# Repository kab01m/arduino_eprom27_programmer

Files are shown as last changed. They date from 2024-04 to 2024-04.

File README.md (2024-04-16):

# EPROM 27-series Arduino-based programmer

Work in-progress of a project of easy-to-use programmer for EPROM 27-series based on Arduino.

*Download GUI application and Arduino sketch from "Releases".*

Supported chips:
 * 27C16 (connects from 3 to 26 leg DIP28 socket)
 * 27C32 (connects from 3 to 26 leg DIP28 socket)
 * 27C64
 * 27C128
 * 27C256
 * 27C512
 * Dallas DS1225 NVRAM

## Installation

Order PCB from gerber files, assemble the board. Use BOM to find components.

If non-Arduino MCU was used you have to flash bootloader from Arduino IDE using ICSP connector. 

If first time assembled you have to load sketch.ino into Arduino IDE and flash your Arduino.

Always check programming voltage before inserting new chip to program.

Run GUI application and choose serial port.

## Schematics

[Initial project](<https://github.com/bouletmarc/BMBurner>):
* Was made in DIP packages.
* No sources.
* Windows-only application.

[Walhi project](<https://github.com/walhi/arduino_eprom27_programmer>):
* Made in Eagle.
* 50/50 SMD/DIP.
* New Arduino sources.
* Windows/Linux Qt-based light GUI application.

[Radionews fork](<https://github.com/Radionews/arduino_eprom27_programmer>):
* Refactored in EasyEDA.
* Uses SPI for logic.
* Mostly SMD components.
* Uses GUI application from above.

[This project](<https://github.com/kab01m/arduino_eprom27_programmer>):
* Translated to KiCad EDA.
* SMD components whereever it was possible.
* Arduino is now not detachable.
* No schematic difference from above.
* Previous software used.

Schematics

Schematic

Assembled picture

PCB

## Software

Software is taken from [Walhi project](<https://github.com/walhi/arduino_eprom27_programmer>).

Functions:

 * Read EEPROM/NVRAM.
 * Write EEPROM/NVRAM.
 * Verify chip and check if it is zeroed.
 * Programming voltage check (available for AVR in TQFP case)

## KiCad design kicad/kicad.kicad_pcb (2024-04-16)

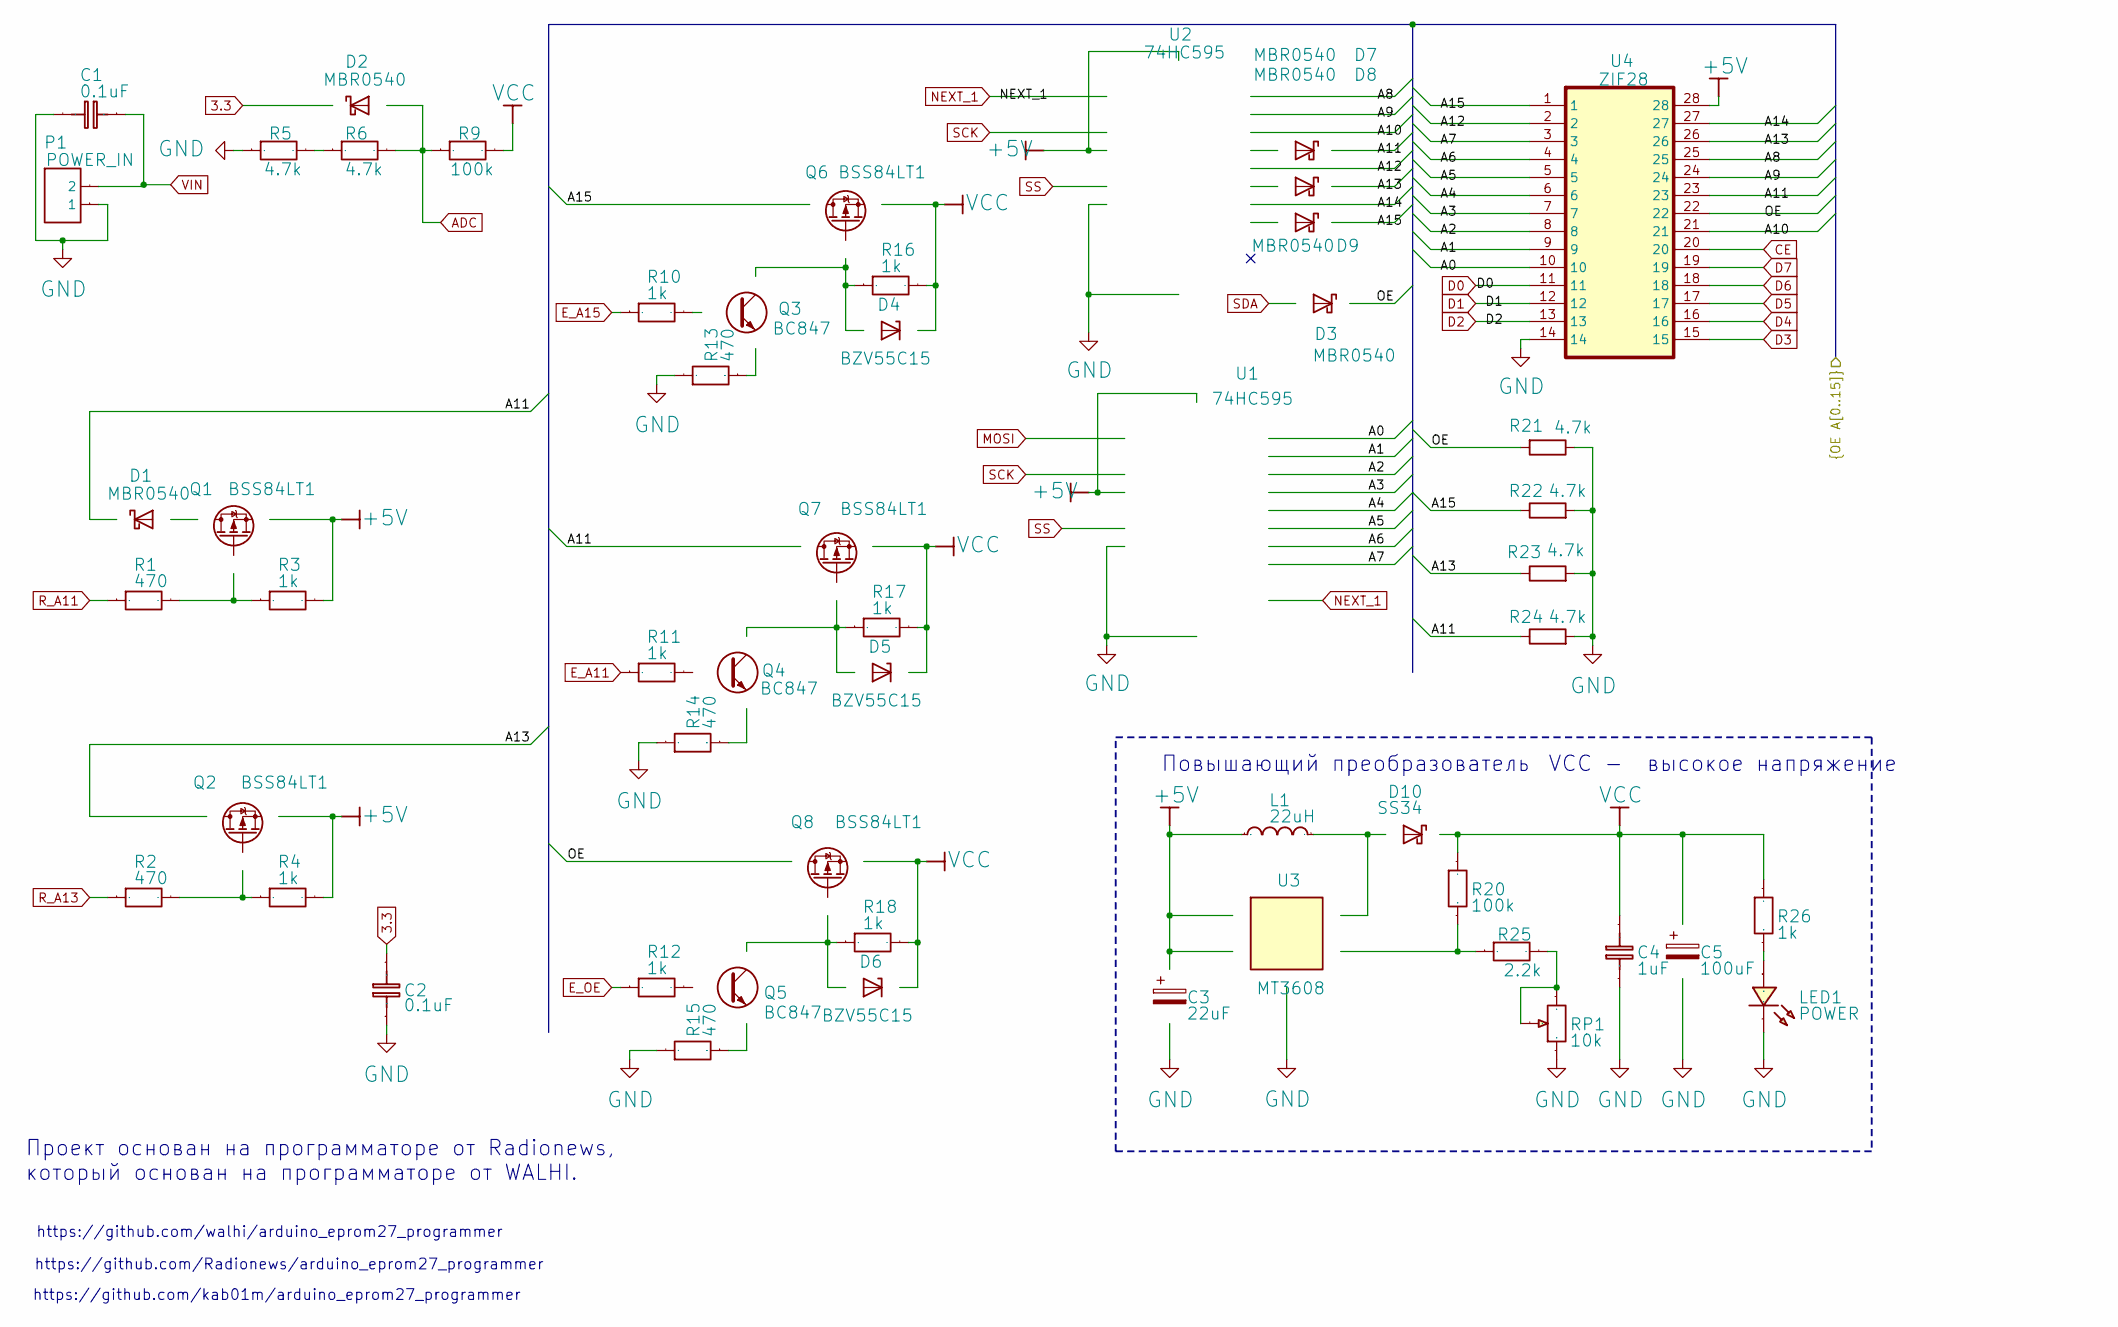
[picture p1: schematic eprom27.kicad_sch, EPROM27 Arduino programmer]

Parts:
C1, C2: 0.1uF; C_0805_2012Metric_Pad1.18x1.45mm_HandSolder
C3: 22uF; CP_Elec_5x5.4
C4: 1uF; C_1206_3216Metric_Pad1.33x1.80mm_HandSolder
C5: 100uF; CP_Elec_8x6.2
D1, D2, D3, D7, D8, D9: MBR0540; D_SOD-123
D4, D5, D6: BZV55C15; D_MiniMELF
D10: SS34; D_SMA
L1: 22uH; L_Chilisin_BMRx00060630
LED1: POWER; LED_0805_2012Metric_Pad1.15x1.40mm_HandSolder
P1: POWER_IN; JST_NV_B02P-NV_1x02_P5.00mm_Vertical
Q1, Q2, Q6, Q7, Q8: BSS84LT1; SOT-23
Q3, Q4, Q5: BC847; SOT-23
R1, R2, R13, R14, R15: 470; R_0805_2012Metric_Pad1.20x1.40mm_HandSolder
R3, R4, R10, R11, R12, R16, R17, R18, R26: 1k; R_0805_2012Metric_Pad1.20x1.40mm_HandSolder
R5, R6, R21, R22, R23, R24: 4.7k; R_0805_2012Metric_Pad1.20x1.40mm_HandSolder
R9, R20: 100k; R_0805_2012Metric_Pad1.20x1.40mm_HandSolder
R25: 2.2k; R_0805_2012Metric_Pad1.20x1.40mm_HandSolder
RP1: 10k; Potentiometer_Bourns_3224W_Vertical
U1, U2: 74HC595; SOIC-16_3.9x9.9mm_P1.27mm
U3: MT3608; SOT-23-6
U4: ZIF28; DIP_Socket-28_W11.9_W12.7_W15.24_W17.78_W18.5_3M_228-1277-0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

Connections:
3.3: C2.2, D2.1 (K); also elsewhere on the board
+5V: C3.1, L1.1, Q1.2 (S), Q2.2 (S), R3.2, R4.2, U1.10 (~SRCLR), U1.16 (VCC), U2.10 (~SRCLR), U2.16 (VCC), U3.4 (EN), U3.5 (IN), U4.28; also elsewhere on the board
/EPROM27/A0: U1.15 (QA), U4.10
/EPROM27/A1: U1.1 (QB), U4.9
/EPROM27/A2: U1.2 (QC), U4.8
/EPROM27/A3: U1.3 (QD), U4.7
/EPROM27/A4: U1.4 (QE), U4.6
/EPROM27/A5: U1.5 (QF), U4.5
/EPROM27/A6: U1.6 (QG), U4.4
/EPROM27/A7: U1.7 (QH), U4.3
/EPROM27/A8: U2.15 (QA), U4.25
/EPROM27/A9: U2.1 (QB), U4.24
/EPROM27/A10: U2.2 (QC), U4.21
/EPROM27/A11: D1.1 (K), D7.1 (K), Q7.3 (D), R24.1, U4.23
/EPROM27/A12: U2.4 (QE), U4.2
/EPROM27/A13: D8.1 (K), Q2.3 (D), R23.1, U4.26
/EPROM27/A14: U2.6 (QG), U4.27
/EPROM27/A15: D9.1 (K), Q6.3 (D), R22.1, U4.1
/EPROM27/OE: D3.1 (K), Q8.3 (D), R21.2, U4.22
ADC: D2.2 (A), R6.2, R9.1; also elsewhere on the board
CE: U4.20; also elsewhere on the board
D0: U4.11; also elsewhere on the board
D1: U4.12; also elsewhere on the board
D2: U4.13; also elsewhere on the board
D3: U4.15; also elsewhere on the board
D4: U4.16; also elsewhere on the board
D5: U4.17; also elsewhere on the board
D6: U4.18; also elsewhere on the board
D7: U4.19; also elsewhere on the board
E_A11: R11.1; also elsewhere on the board
E_A15: R10.1; also elsewhere on the board
E_OE: R12.1; also elsewhere on the board
MISO: R1.1; also elsewhere on the board
MOSI: U1.14 (SER); also elsewhere on the board
NEXT_1: U1.9 (QH'), U2.14 (SER)
unnamed: D1.2 (A), Q1.3 (D)
unnamed: D4.2 (A), Q3.3 (C), Q6.1 (G), R16.1
unnamed: D5.2 (A), Q4.3 (C), Q7.1 (G), R17.1
unnamed: D6.2 (A), Q5.3 (C), Q8.1 (G), R18.1
unnamed: D7.2 (A), U2.3 (QD)
unnamed: D8.2 (A), U2.5 (QF)
unnamed: D9.2 (A), U2.7 (QH)
unnamed: D10.2 (A), L1.2, U3.1 (SW)
unnamed: LED1.1, R26.1
unnamed: Q1.1 (G), R1.2, R3.1
unnamed: Q2.1 (G), R2.2, R4.1
unnamed: Q3.1 (B), R10.2
unnamed: Q3.2 (E), R13.1
unnamed: Q4.1 (B), R11.2
unnamed: Q4.2 (E), R14.1
unnamed: Q5.1 (B), R12.2
unnamed: Q5.2 (E), R15.1
unnamed: R5.2, R6.1
unnamed: R25.2, RP1.2, RP1.3
unnamed: R20.1, R25.1, U3.3 (FB)
R_A13: R2.1; also elsewhere on the board
SCK: U1.11 (SRCLK), U2.11 (SRCLK); also elsewhere on the board
SDA: D3.2 (A); also elsewhere on the board
SS: U1.12 (RCLK), U2.12 (RCLK); also elsewhere on the board
VCC: C4.2, C5.1, D4.1 (K), D5.1 (K), D6.1 (K), D10.1 (K), Q6.2 (S), Q7.2 (S), Q8.2 (S), R9.2, R16.2, R17.2, R18.2, R20.2, R26.2
VIN: C1.1, P1.2; also elsewhere on the board

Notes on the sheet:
https://github.com/walhi/arduino_eprom27_programmer
Проект основан на программаторе от Radionews, который основан на программаторе от WALHI.
VCC - высокое напряжение
Повышающий преобразователь
https://github.com/Radionews/arduino_eprom27_programmer
https://github.com/kab01m/arduino_eprom27_programmer

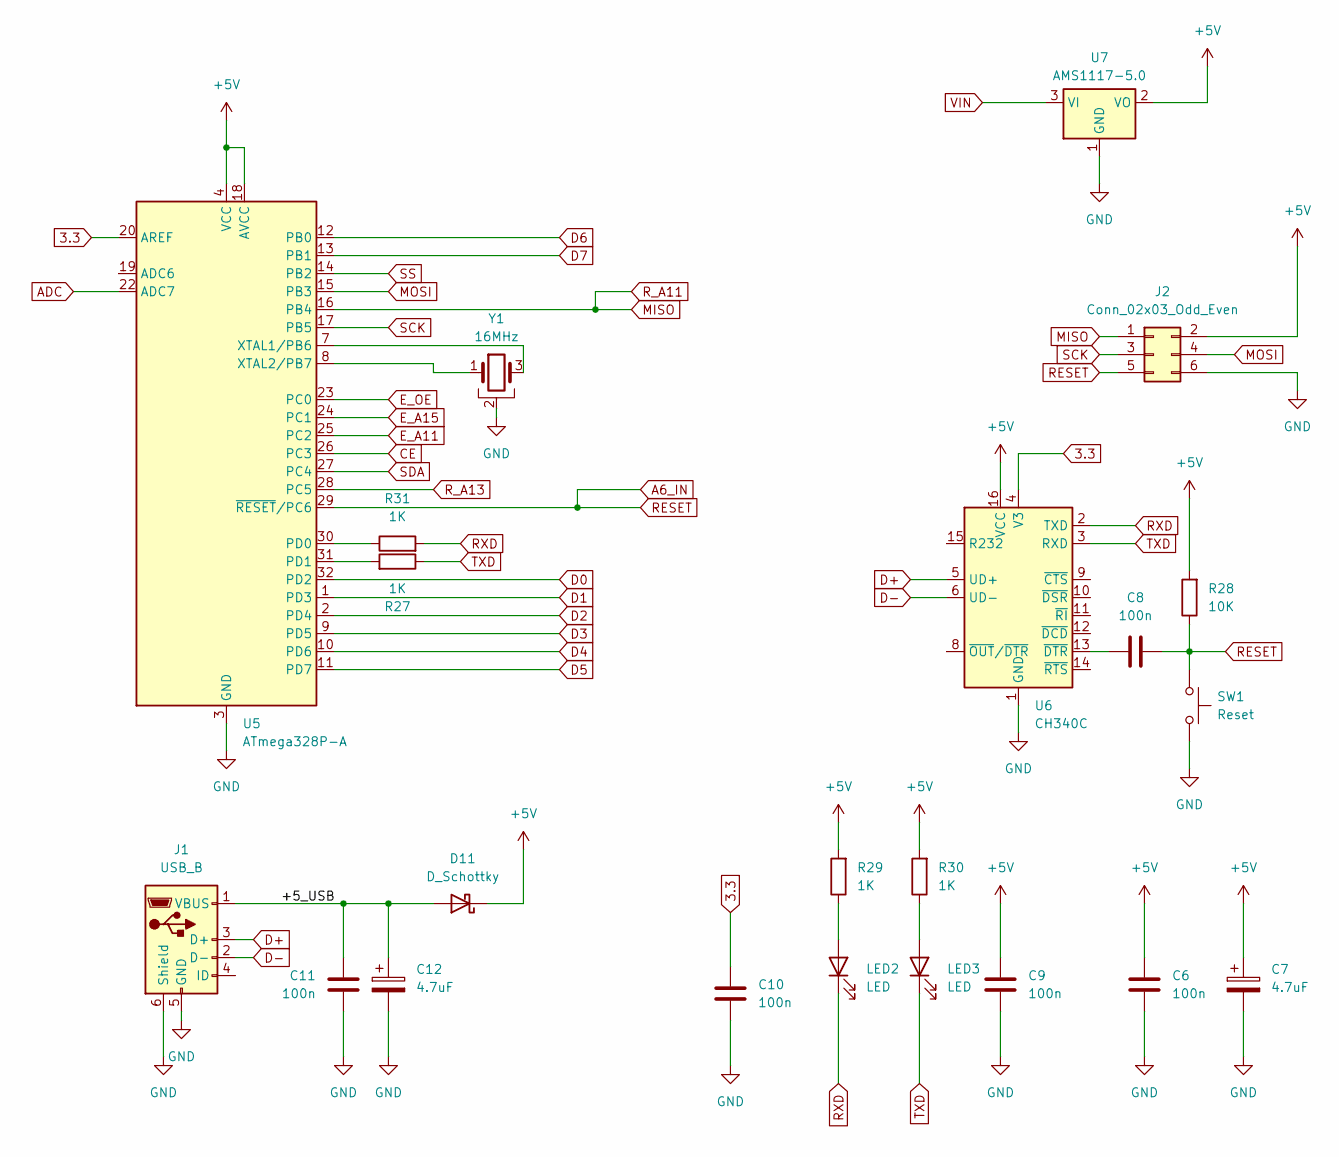
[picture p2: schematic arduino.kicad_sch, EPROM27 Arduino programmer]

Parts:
C6, C8, C9, C10, C11: 100n; C_0805_2012Metric_Pad1.18x1.45mm_HandSolder
C7, C12: 4.7uF; CP_EIA-3216-18_Kemet-A_Pad1.58x1.35mm_HandSolder
D11: D_Schottky; D_SOD-323_HandSoldering
J1: USB_B; USB_Mini-B_Lumberg_2486_01_Horizontal
J2: Conn_02x03_Odd_Even; PinHeader_2x03_P2.54mm_Vertical
LED2, LED3: LED; LED_0805_2012Metric_Pad1.15x1.40mm_HandSolder
R27, R29, R30, R31: 1K; R_0805_2012Metric_Pad1.20x1.40mm_HandSolder
R28: 10K; R_0805_2012Metric_Pad1.20x1.40mm_HandSolder
SW1: Reset; SW_SPST_TL3342
U5: ATmega328P-A; TQFP-32_7x7mm_P0.8mm
U6: CH340C; SOIC-16_3.9x9.9mm_P1.27mm
U7: AMS1117-5.0; SOT-223-3_TabPin2
Y1: 16MHz; Resonator_SMD_Murata_CSTxExxV-3Pin_3.0x1.1mm

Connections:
3.3: C10.1, U5.20 (AREF), U6.4 (V3); also elsewhere on the board
+5V: C6.1, C7.1, C9.1, D11.1 (K), J2.2, R28.2, R29.2, R30.2, U5.4 (VCC), U5.6 (VCC), U5.18 (AVCC), U6.16 (VCC), U7.2 (VO); also elsewhere on the board
/Arduino/+5_USB: C11.1, C12.1, D11.2 (A), J1.1 (VBUS)
A6_IN: C8.2, J2.5, R28.1, SW1.1, U5.29 (~RESET/PC6)
ADC: U5.22 (ADC7); also elsewhere on the board
CE: U5.26 (PC3); also elsewhere on the board
D0: U5.32 (PD2); also elsewhere on the board
D1: U5.1 (PD3); also elsewhere on the board
D2: U5.2 (PD4); also elsewhere on the board
D3: U5.9 (PD5); also elsewhere on the board
D4: U5.10 (PD6); also elsewhere on the board
D5: U5.11 (PD7); also elsewhere on the board
D6: U5.12 (PB0); also elsewhere on the board
D7: U5.13 (PB1); also elsewhere on the board
D+: J1.3 (D+), U6.5 (UD+)
D-: J1.2 (D-), U6.6 (UD-)
E_A11: U5.25 (PC2); also elsewhere on the board
E_A15: U5.24 (PC1); also elsewhere on the board
E_OE: U5.23 (PC0); also elsewhere on the board
MISO: J2.1, U5.16 (PB4); also elsewhere on the board
MOSI: J2.4, U5.15 (PB3); also elsewhere on the board
unnamed: LED2.2 (A), R29.1
unnamed: LED3.2 (A), R30.1
unnamed: R31.1, U5.30 (PD0)
unnamed: R27.2, U5.31 (PD1)
unnamed: U5.7 (XTAL1/PB6), Y1.3
unnamed: U5.8 (XTAL2/PB7), Y1.1
unnamed: C8.1, U6.13 (~DTR)
RXD: LED2.1 (K), R31.2, U6.2 (TXD)
R_A13: U5.28 (PC5); also elsewhere on the board
SCK: J2.3, U5.17 (PB5); also elsewhere on the board
SDA: U5.27 (PC4); also elsewhere on the board
SS: U5.14 (PB2); also elsewhere on the board
TXD: LED3.1 (K), R27.1, U6.3 (RXD)
VIN: U7.3 (VI); also elsewhere on the board

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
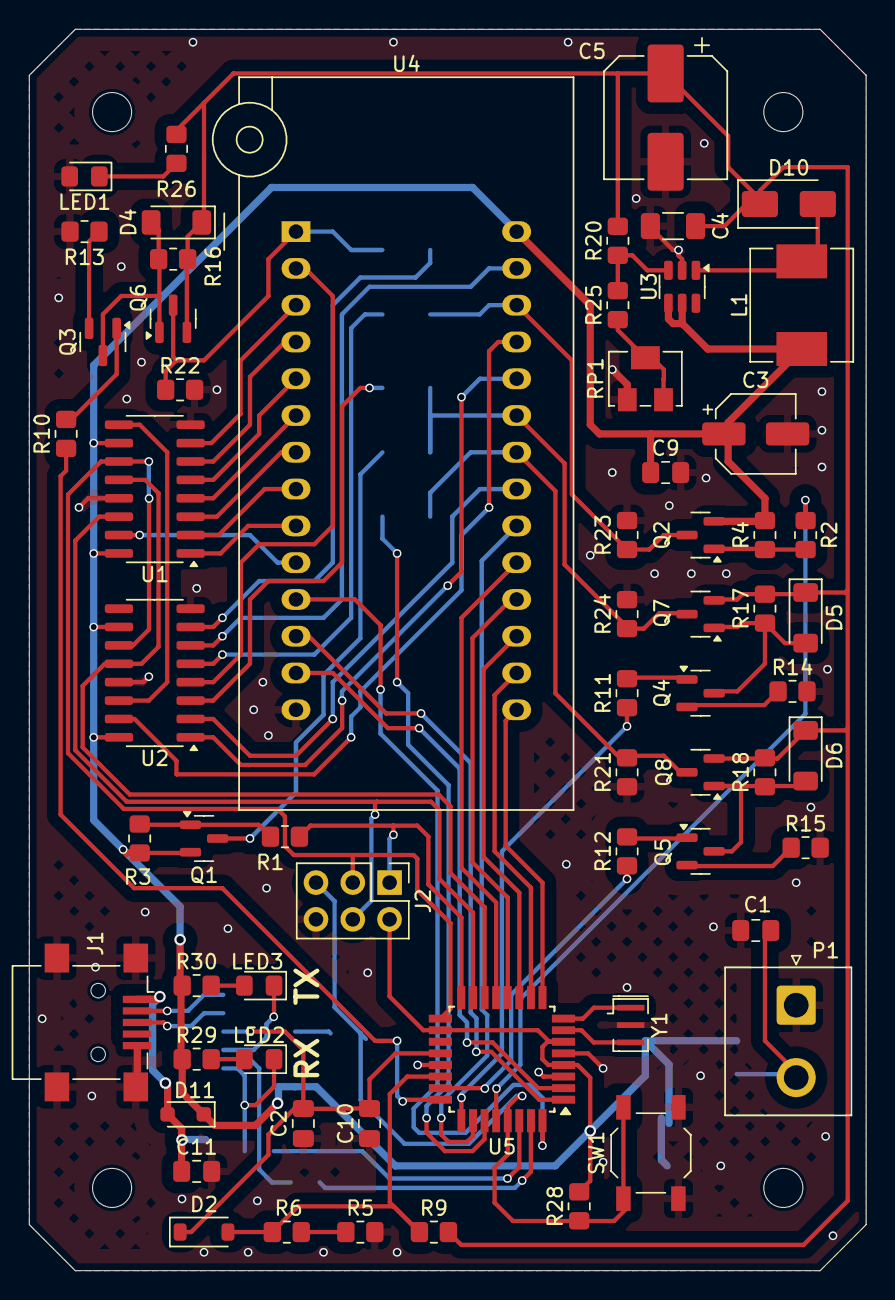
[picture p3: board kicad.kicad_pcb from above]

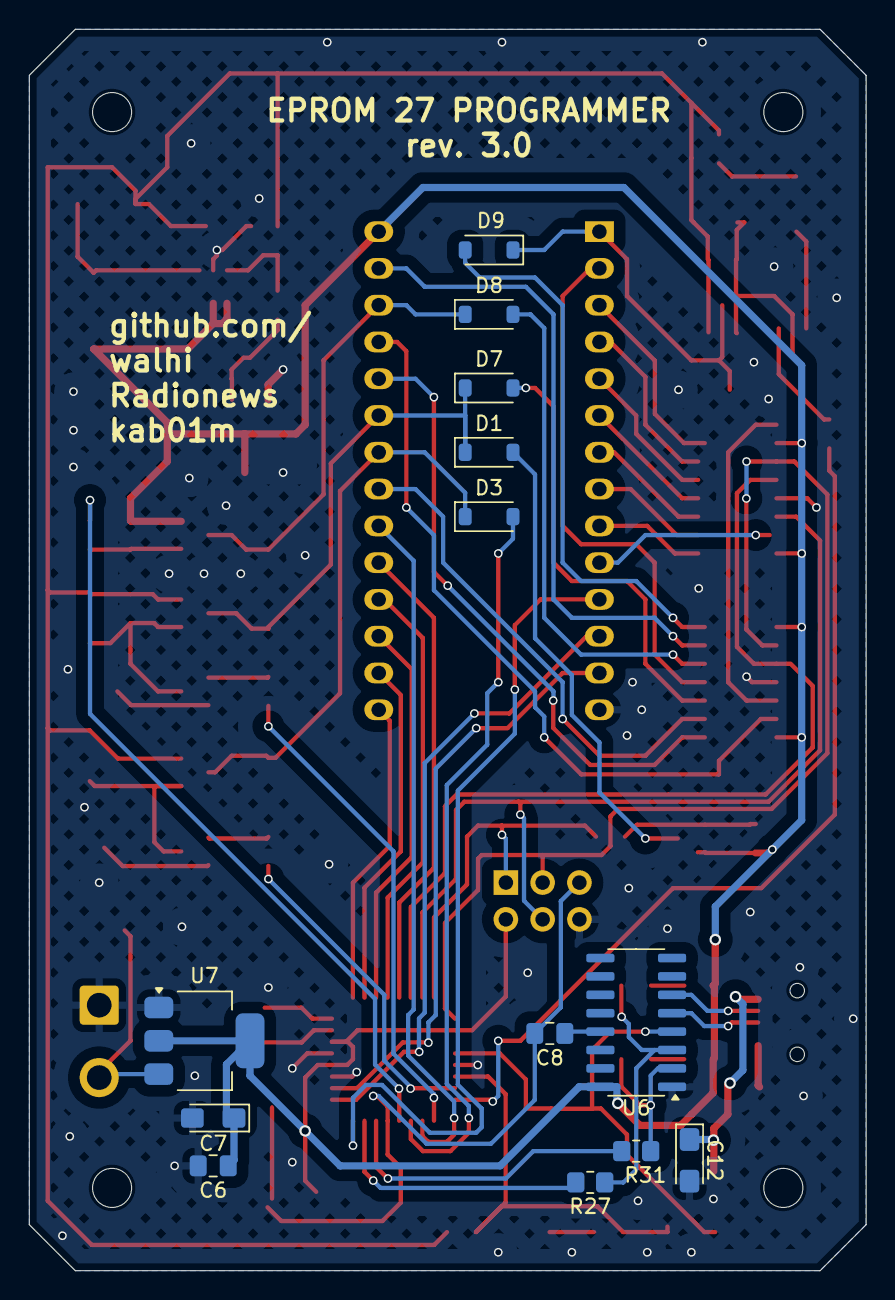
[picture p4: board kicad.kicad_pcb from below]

Board: 2 copper layers, 57.8 x 85.7 mm, 76 parts (13 on the bottom side), 75 nets.

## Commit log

2024-03-21 Schematics and first board
    [arduino.kicad_sch, eprom27.kicad_sch, kicad.kicad_pcb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]
2024-04-16 Small pre-release fixes
    [arduino.kicad_sch, eprom27.kicad_sch, kicad.kicad_pcb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]
